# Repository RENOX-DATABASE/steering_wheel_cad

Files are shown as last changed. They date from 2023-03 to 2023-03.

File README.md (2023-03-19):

# Steering Wheel CAD DATA and Manual
The purpose is to share technology and knowledge, and it is for non-commercial purposes.

**Copyright 2023, RENOX**</br>
Subject to the existing rights of third parties, RENOX is the owner of the copyright in this work, and no portion hereof is to be copied, reproduced, or disseminated without the prior written consent of RENOX.

---
**GitLink**<br>
**Designed by RENOX**

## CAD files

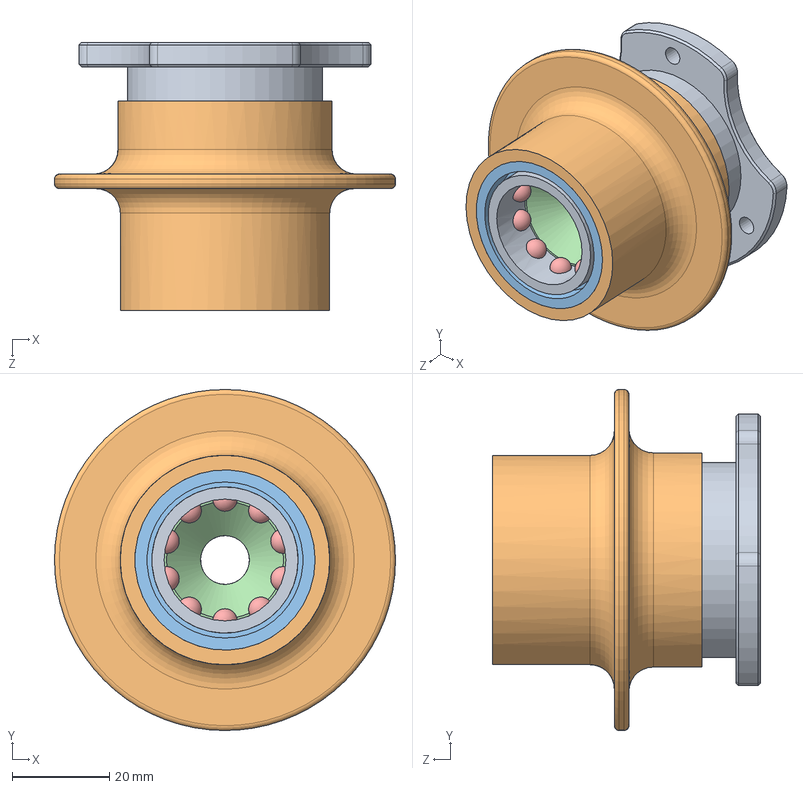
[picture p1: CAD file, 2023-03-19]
Quick Release 1.SLDASM
70.0 x 70.0 x 55.0 mm
Spring 1
Spring 2

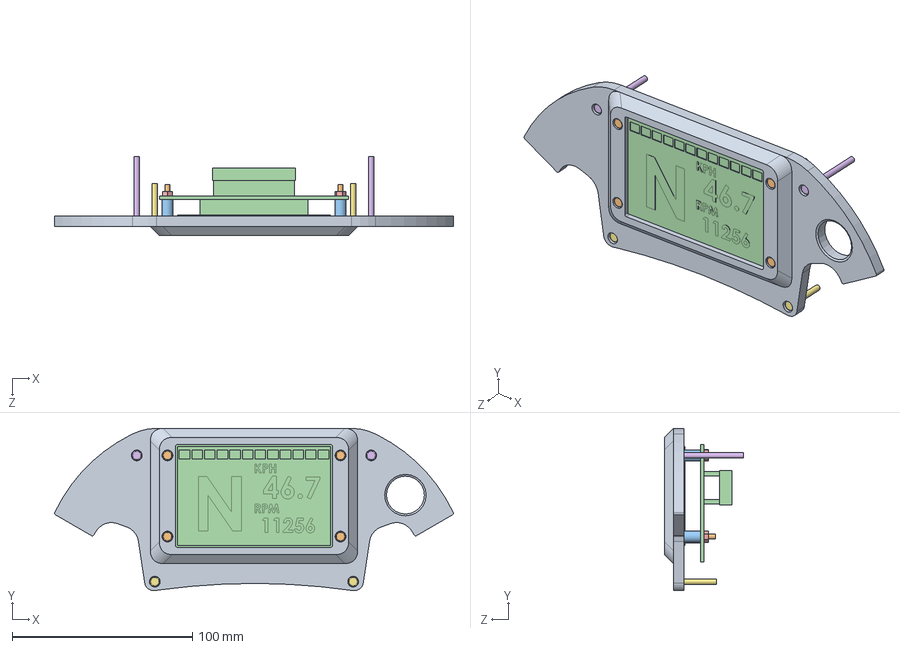
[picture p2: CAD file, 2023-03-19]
RF019 SWMB&AM.SLDASM
221.3 x 90.0 x 44.0 mm
RF019 SWMB kai
M3 25 Bolt x 4
RF018 Spacer for SWMB[M3 9] x 4
RF019 AC kai Display
M3 Nat x 4
M3 35 Bolt x 2
M3 20 Bolt x 2

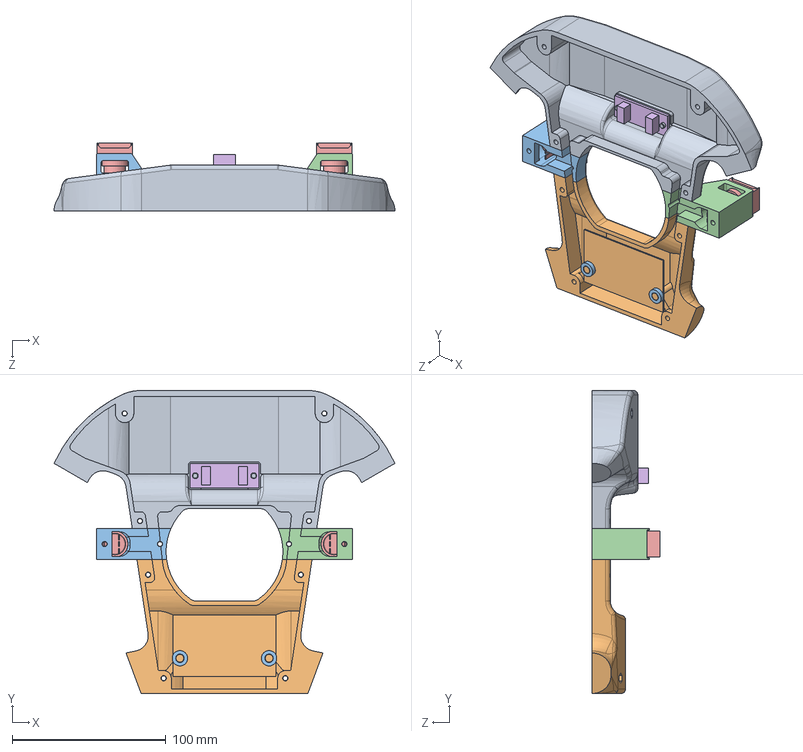
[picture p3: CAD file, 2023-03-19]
RF019 SWB&PSM.SLDASM
221.9 x 197.3 x 44.5 mm
RF019 SWB kai B1
RF019 SWB kai B3
RF019 SWB PSMB2L kai
RF019 SWB PSMB2R kai
RF018 IDEC Switch x 2
RF019 CC
M3 Nat x 12
M2 Nat x 2
M2 8 Bolt x 2
RF019 SC kai
RF018 Spacer for Shifter Circle[Φ5 3] x 2

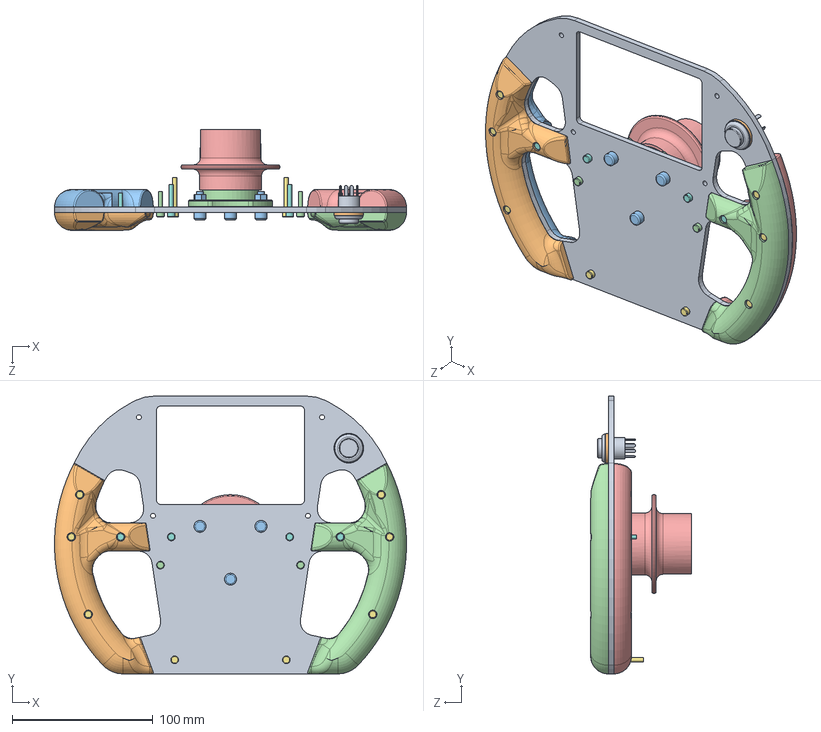
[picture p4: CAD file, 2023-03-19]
RF019 SWCP&G.SLDASM
249.9 x 197.3 x 71.5 mm
RF019 SWCP kai
RF019 SWG kai LF
RF019 SWG kai LR
RF019 SWG kai RF
RF019 SWG kai RR
M3 Nat x 6
M3 25 Bolt x 8
M3 20 Bolt x 4
RF018 Paddle Shift Adapt Switch
RF018 Spacer for PSA Switch
M5 20 Bolt x 3
Spring 1
Spring 2
M5 Nat x 3
M3 15 Bolt x 2

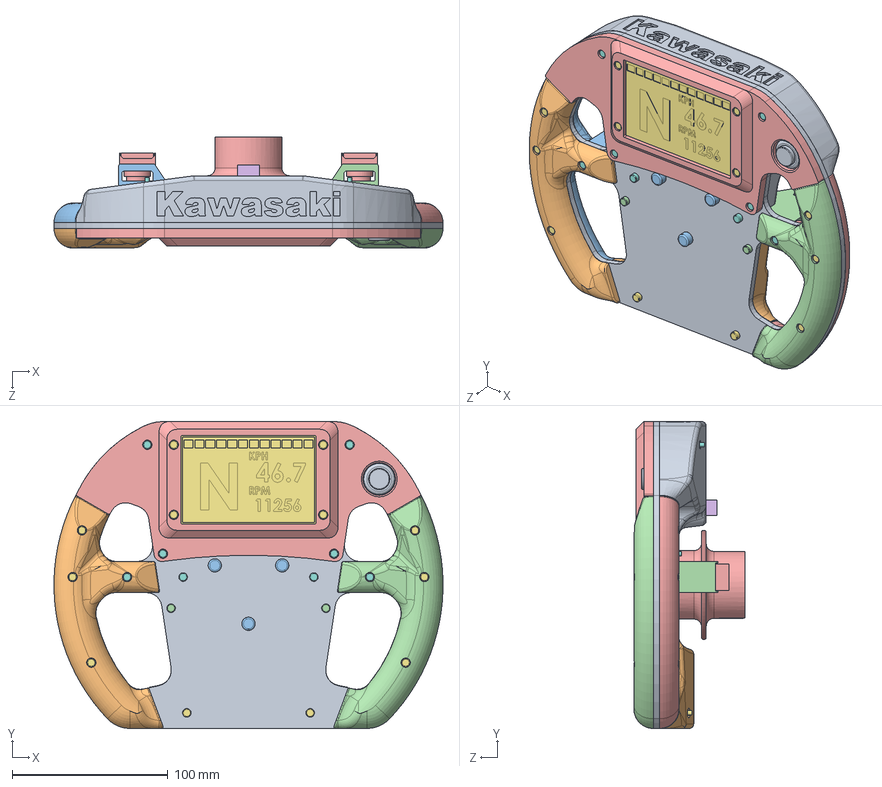
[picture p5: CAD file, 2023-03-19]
RF019 SW Assem.SLDASM
249.9 x 197.3 x 71.5 mm
RF019 SWCP kai
RF019 SWG kai LF
RF019 SWG kai LR
RF019 SWG kai RF
RF019 SWG kai RR
M3 Nat x 22
M3 25 Bolt x 12
M3 20 Bolt x 6
RF018 Paddle Shift Adapt Switch
RF018 Spacer for PSA Switch
M5 20 Bolt x 3
Spring 1
Spring 2
M5 Nat x 3
M3 15 Bolt x 2
RF019 SWMB kai
RF018 Spacer for SWMB[M3 9] x 4
RF019 AC kai Display
M3 35 Bolt x 2
RF019 SWB kai B1
RF019 SWB kai B3
RF019 SWB PSMB2L kai
RF019 SWB PSMB2R kai
RF018 IDEC Switch x 2
RF019 CC
M2 Nat x 2
M2 8 Bolt x 2
RF019 SC kai
RF018 Spacer for Shifter Circle[Φ5 3] x 2

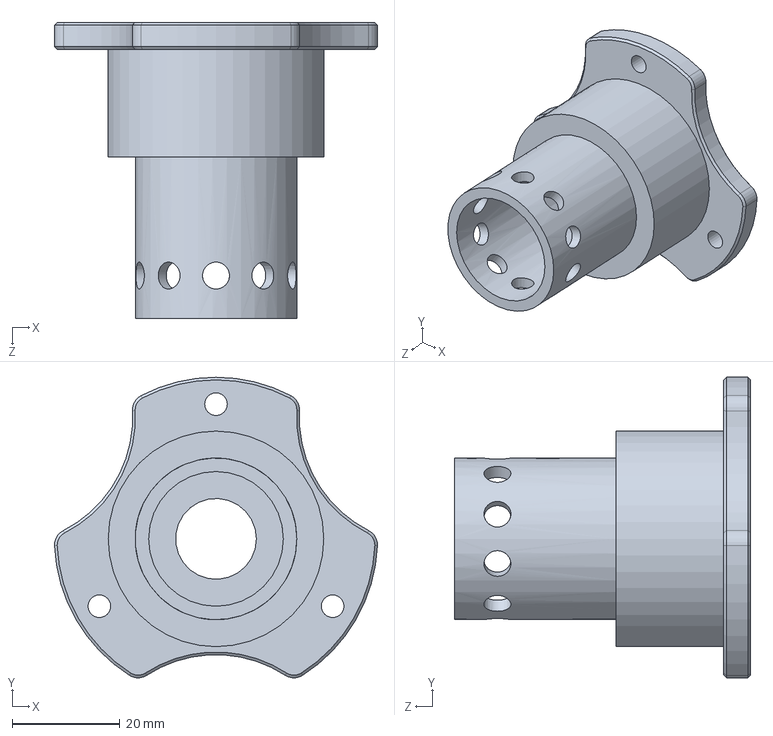
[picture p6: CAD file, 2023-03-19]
1-1.SLDPRT
59.9 x 55.8 x 55.0 mm

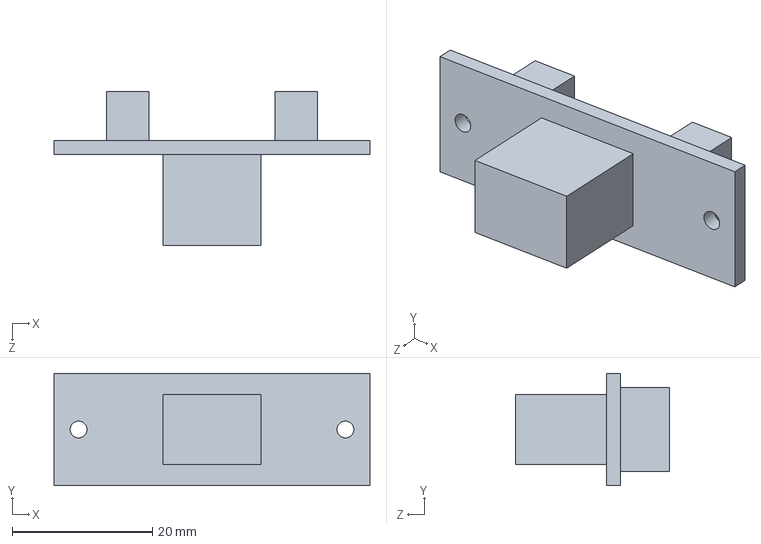
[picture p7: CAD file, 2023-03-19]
RF019 CC.SLDPRT
45.0 x 16.0 x 22.0 mm

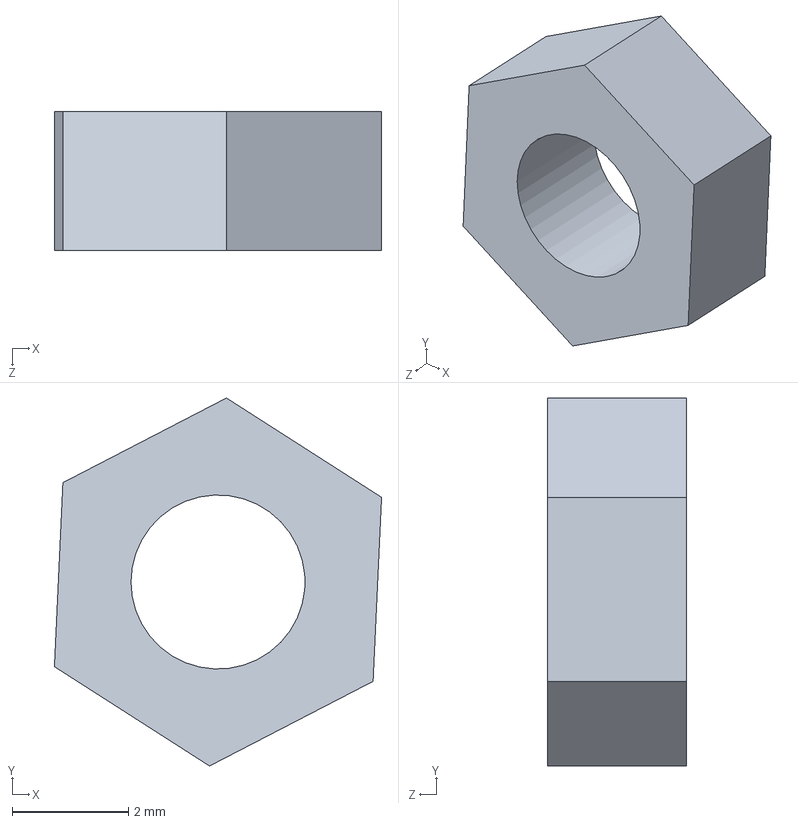
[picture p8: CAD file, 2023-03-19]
M3 Nat.SLDPRT
5.64 x 6.34 x 2.40 mm

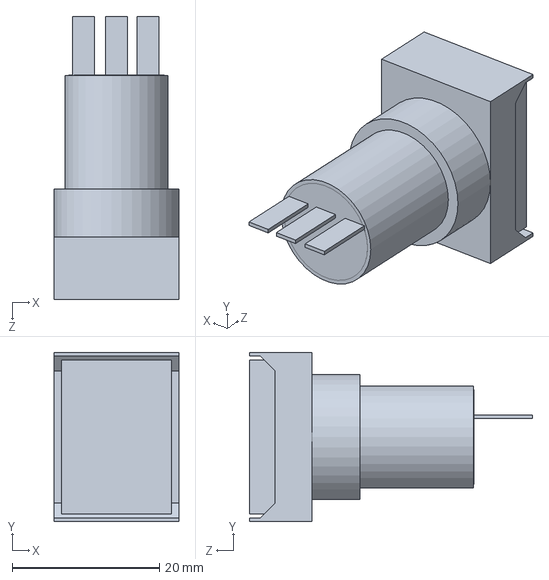
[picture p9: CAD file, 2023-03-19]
RF018 IDEC Switch.SLDPRT
17.0 x 23.0 x 38.5 mm

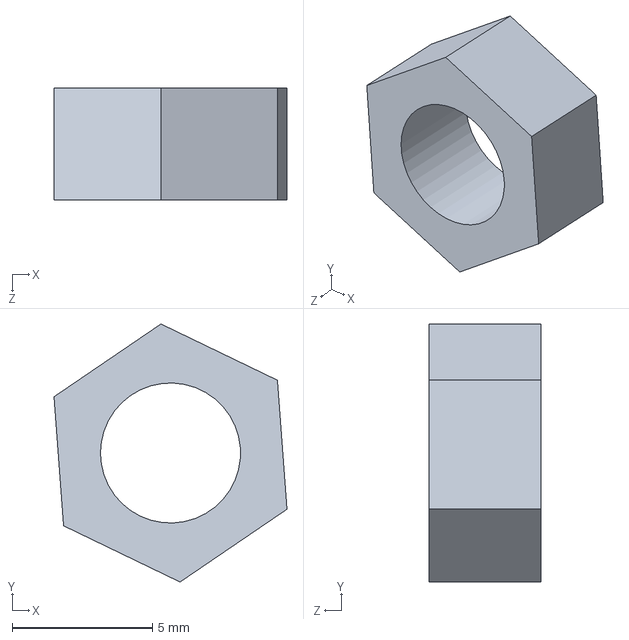
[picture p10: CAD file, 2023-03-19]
M5 Nat.SLDPRT
8.32 x 9.21 x 4.00 mm

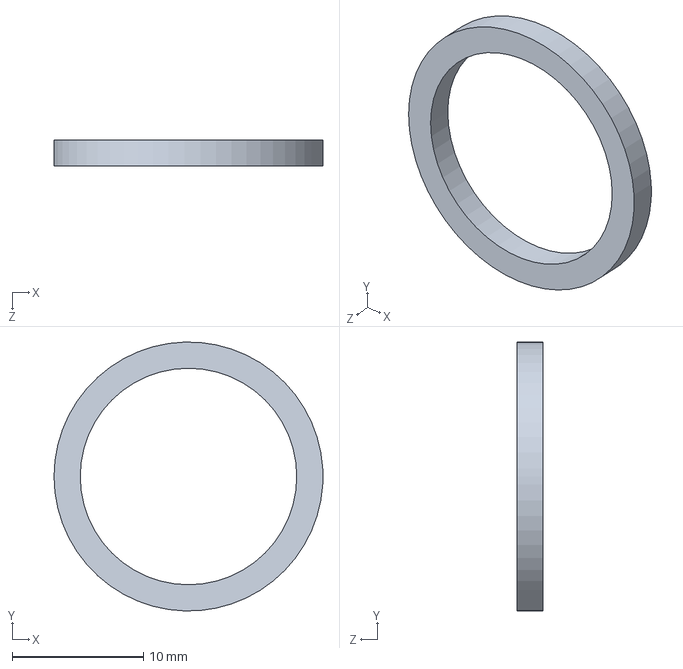
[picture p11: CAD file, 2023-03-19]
RF018 Spacer for PSA Switch.SLDPRT
20.5 x 20.5 x 2.00 mm

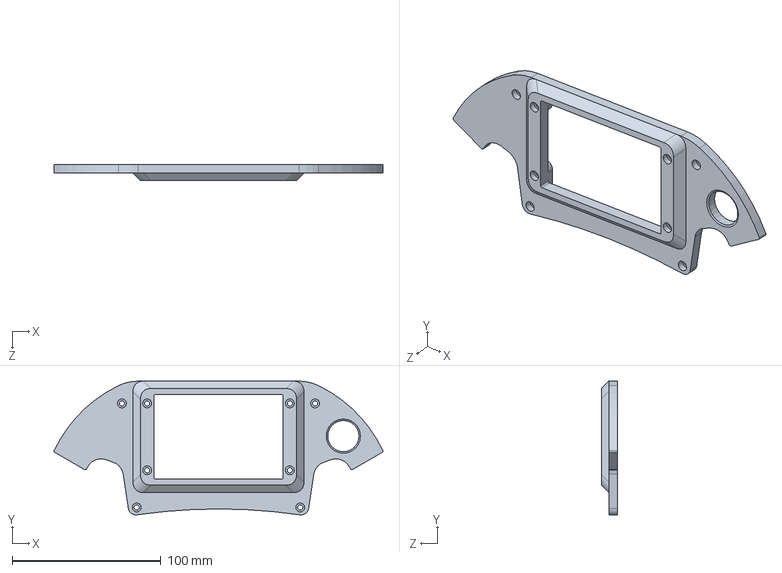
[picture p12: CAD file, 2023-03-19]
RF019 SWMB kai.SLDPRT
221.3 x 90.0 x 11.0 mm

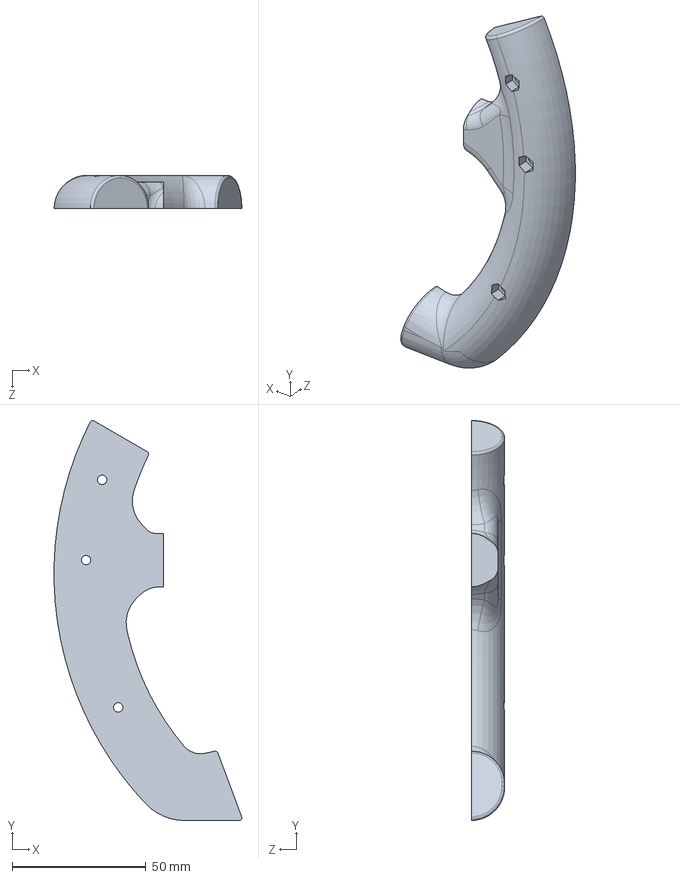
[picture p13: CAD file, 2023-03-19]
RF019 SWG kai LR.SLDPRT
70.2 x 149.4 x 12.5 mm

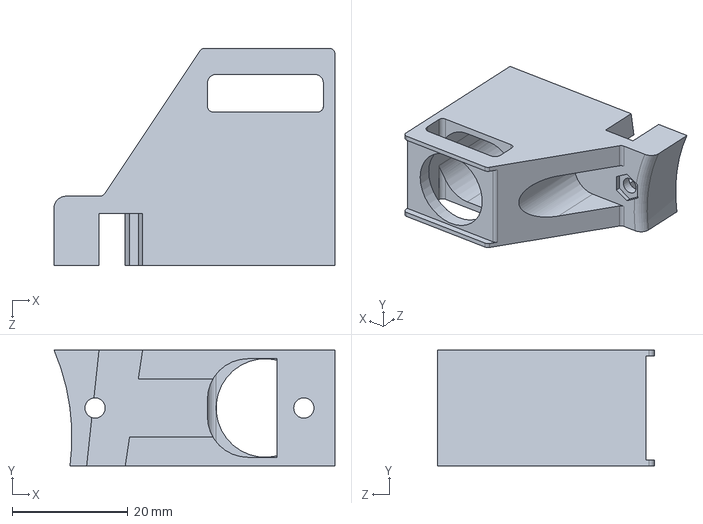
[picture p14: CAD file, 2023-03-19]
RF019 SWB PSMB2R kai.SLDPRT
48.5 x 20.0 x 37.5 mm

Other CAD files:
RF019 SWG kai RR.SLDPRT
Spring 1.SLDPRT
RF018 Spacer for Shifter Circle[Φ5 3].SLDPRT
1-2.SLDPRT
1-3.SLDPRT
1-4.SLDPRT
1-5.SLDPRT
M2 8 Bolt.SLDPRT
M2 Nat.SLDPRT
M3 15 Bolt.SLDPRT
M3 20 Bolt.SLDPRT
M3 25 Bolt.SLDPRT
M3 35 Bolt.SLDPRT
M5 20 Bolt.SLDPRT
RF018 Paddle Shift Adapt Switch.SLDPRT
RF018 Spacer for SWMB[M3 9].SLDPRT
RF019 AC kai Display.SLDPRT
RF019 SC kai.SLDPRT
RF019 SWB PSMB2L kai.SLDPRT
RF019 SWB kai B1.SLDPRT
RF019 SWB kai B3.SLDPRT
RF019 SWCP kai.SLDPRT
RF019 SWG kai LF.SLDPRT
RF019 SWG kai RF.SLDPRT
Spring 2.SLDPRT

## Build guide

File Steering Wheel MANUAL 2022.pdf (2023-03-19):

# S T E E R I N G W H E E L M A N U A L 2 0 2 2

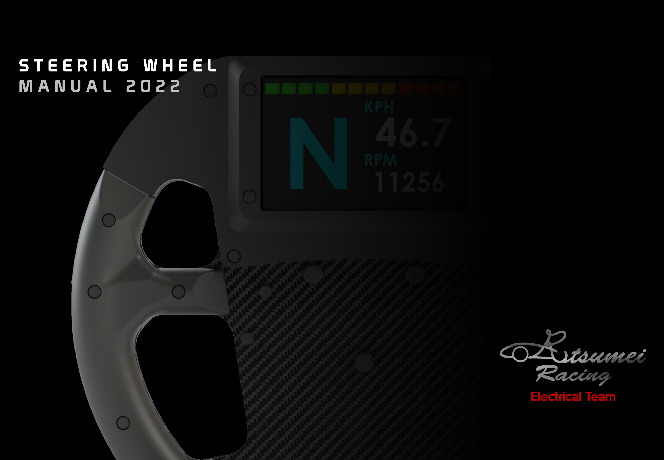
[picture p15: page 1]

## Electrical Team

# C o n t e n t s

このマニュアルはRitsumei Racingで設計されたステアリング ホイールの概要と組み立て方法を説明するものである。当初はス マートフォンにメーターを表示するアプリを開発しようとしてい た。メーターの目的はエンデュランスで電光掲示板に表示される ラップタイムをドライバー以外の人がスマートフォンに送信する ことであったが、完成しなかった。今回、アプリ開発や通信が難 しいと考え、マイコンを使った自作ディスプレイメーターに変更 し製作した。今回の目的はアクセラレーションにおけるシフトポ ジションと回転数の表示、スキッドパッドにおける車速表示、 オートクロス・エンデュランスにおけるシフトポジション表示で ある。

ステアリングホイールの構成部品について以下に示す。
ステアリングホイールのフレームはカーボンシートを16枚積 層しKitMillの超硬合金エンドミルで切して製作されたが、製作過 程で少し反ってしまっている。
PCBはElecrowに発注した。ただし、素子のはんだ付けは Elecrowでは行われない。
グリップやカバーなどは全てAIOL(イーストウィング1F)の3D プリンター(MakerBot)で製作した。
締結部品はねじの山崎で購入し、スイッチ類はMISUMIで購入 した。他の部品は適宜購入した。

P C B
Connector Module
Shifter Module
Display Module
S y s t e m
Indicator System (RF-018)
Indicator System (RF-019)
Steering Wheel
F u t u r e W o r k
Insert Nut化
STM32 Micro Computer化
LEDタコメータのチップLED化
電源安定化供給
外部接続コネクタのRAPFIX Quick Release化 F i n i s h e d P a r t

## Key

## Manufacturing Error

## Warning

## Point

## Contact Us

## https://qiita.com/RENOX https://github.com/RENOX-DATABASE

Ritsumei Racing
Designed by RENOX

# PCB

# Connector Module

## PCB

2. Power & Others Connector 4 Pin XH Connector × 2

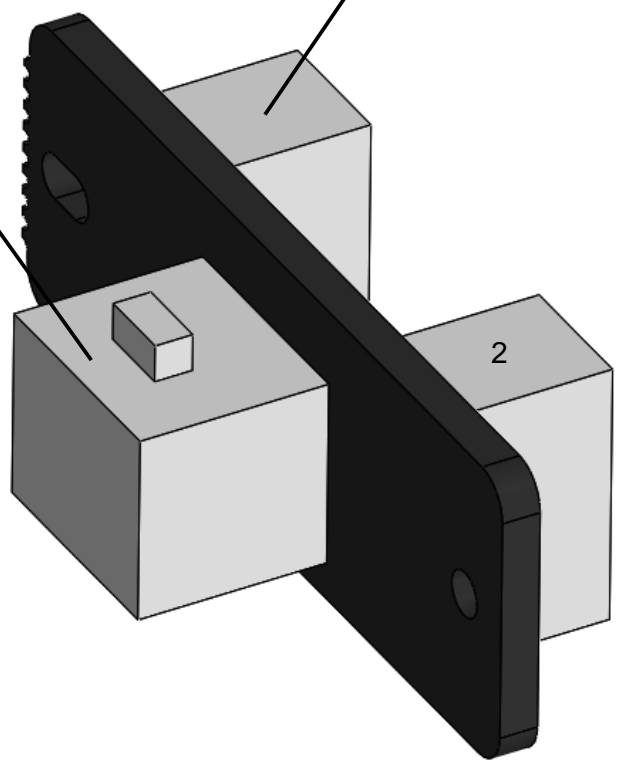
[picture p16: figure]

1. Outside Connector
Molex 6 Pin Mini-Fit-Jr
① | ②
④ | ⑤

③

1
2

※順不同(EAGLEデータ参照)
① 7~12 V
② GND
③ Shift Position Sensor
④ RPM Sensor
⑤ Solenoid Valve 1
⑥ Solenoid Valve 2

⑦
⑧
⑨
⑩

⑥

⑦ ⑧ ⑨ ⑩

Display Module及びShifter
Module のPower&Others Co
nectorに合わせること。

# Connector Module

## PCB

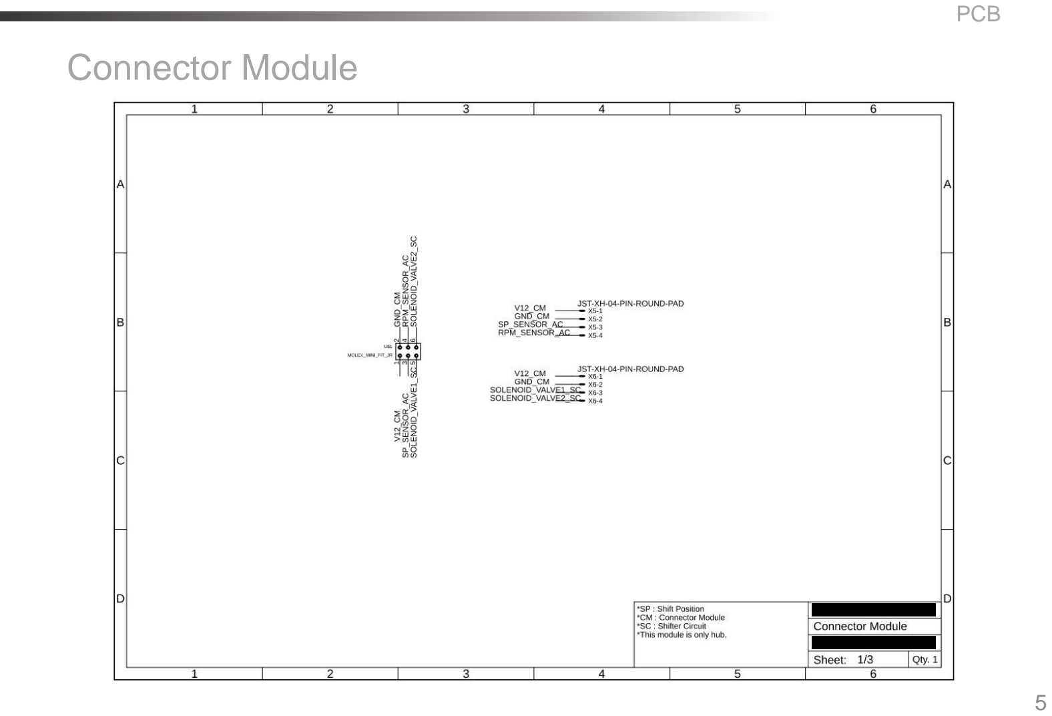
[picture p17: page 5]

# Shifter Module

## PCB

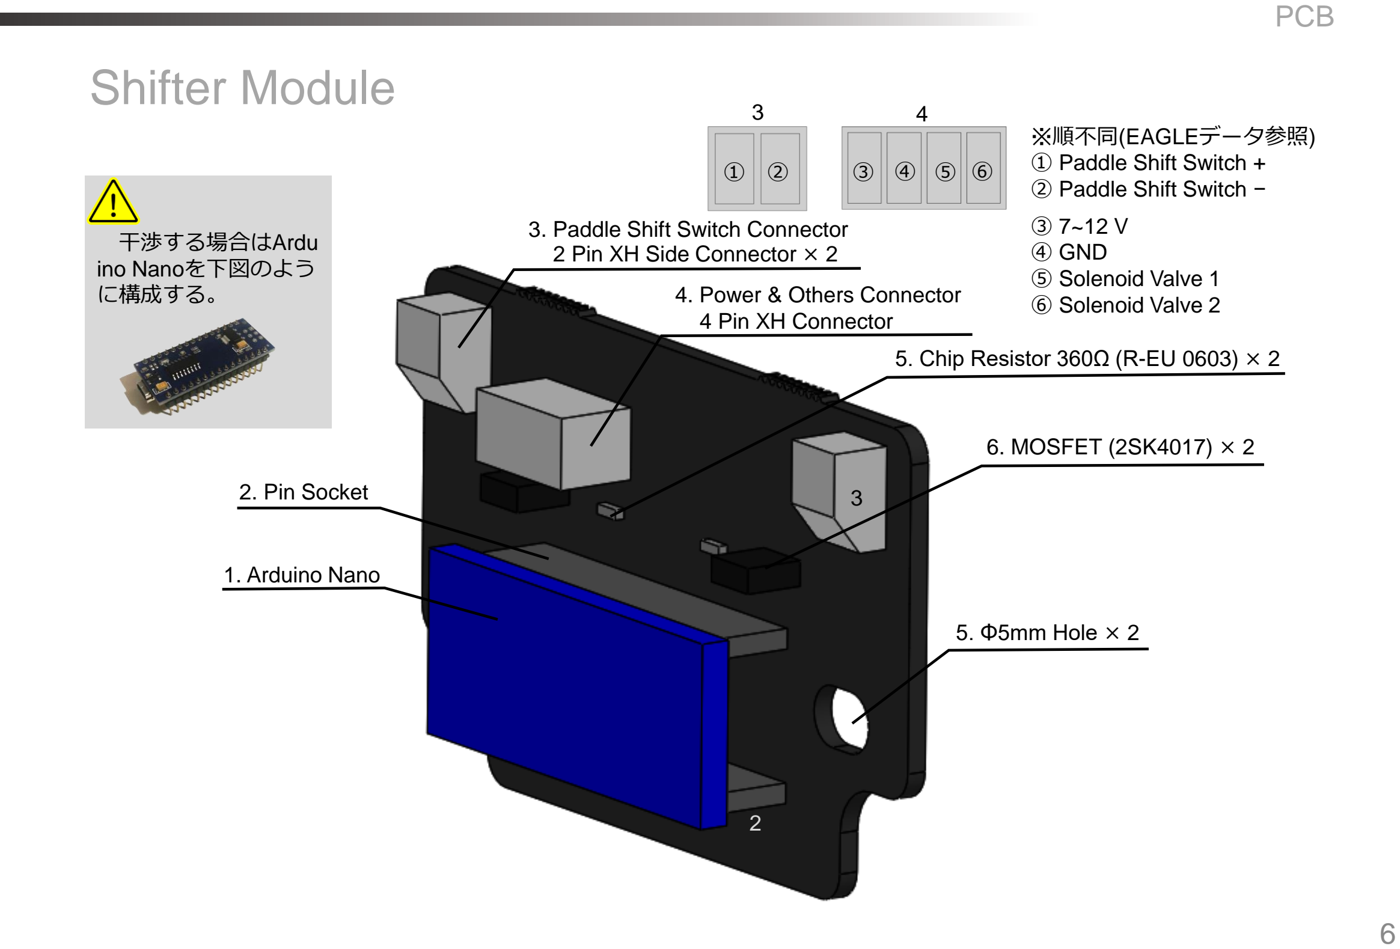
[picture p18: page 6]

5. Φ5mm Hole × 2
2. Pin Socket
1. Arduino Nano
3. Paddle Shift Switch Connector 2 Pin XH Side Connector × 2
4. Power & Others Connector 4 Pin XH Connector

3

2

干渉する場合はArdu
ino Nanoを下図のよう
に構成する。
6. MOSFET (2SK4017) × 2
5. Chip Resistor 360Ω (R-EU 0603) × 2
① ② | ③ ④ ⑤
3 | 4
※順不同(EAGLEデータ参照)
① Paddle Shift Switch +
② Paddle Shift Switch −

③ 7~12 V
④ GND
⑤ Solenoid Valve 1
⑥ Solenoid Valve 2

⑥

# Shifter Module

## PCB

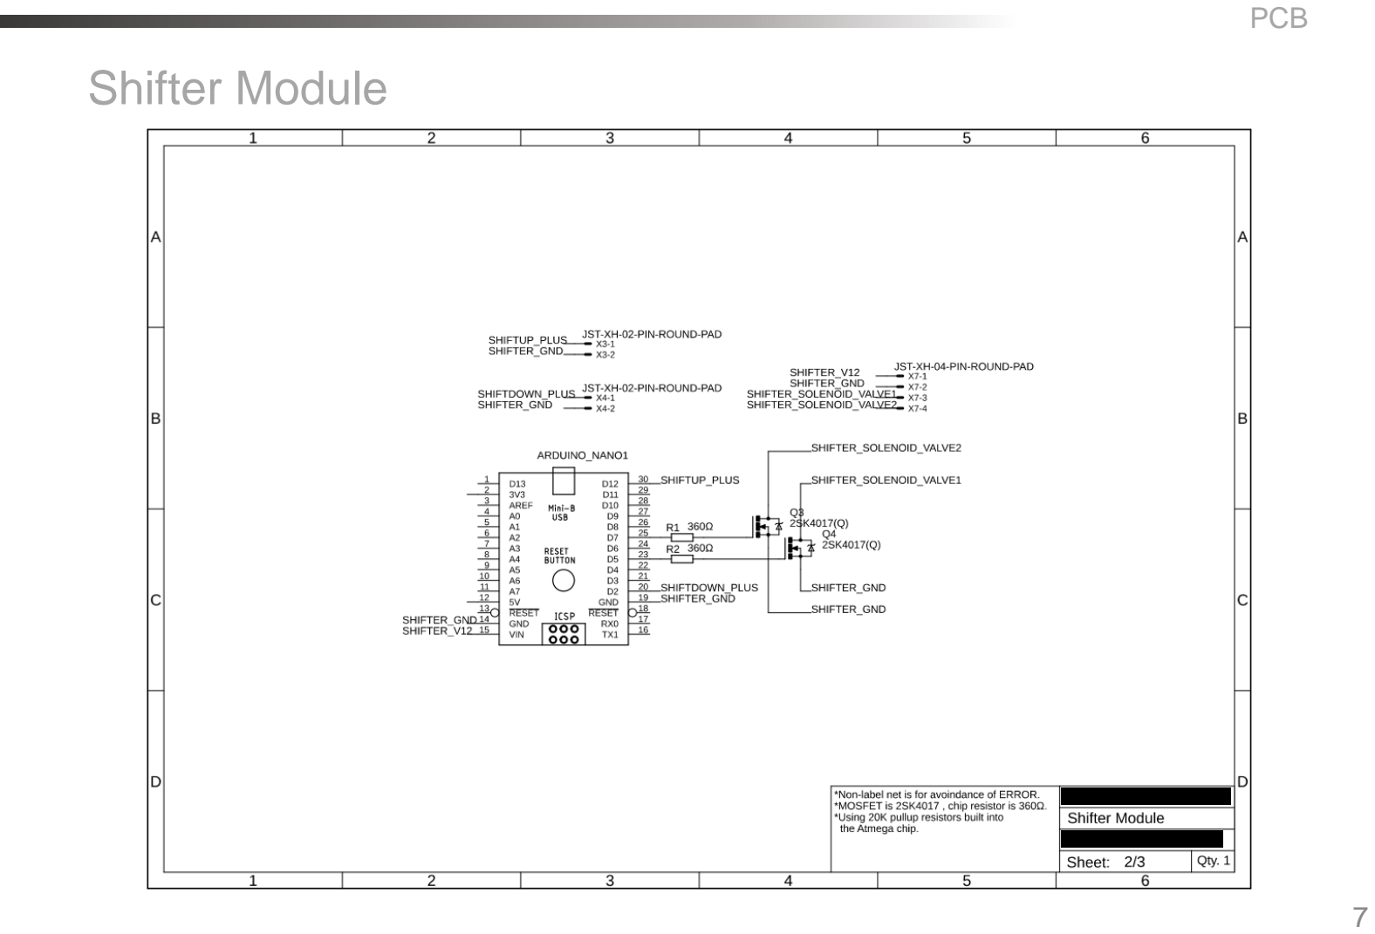
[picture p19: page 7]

# Display Module

## PCB

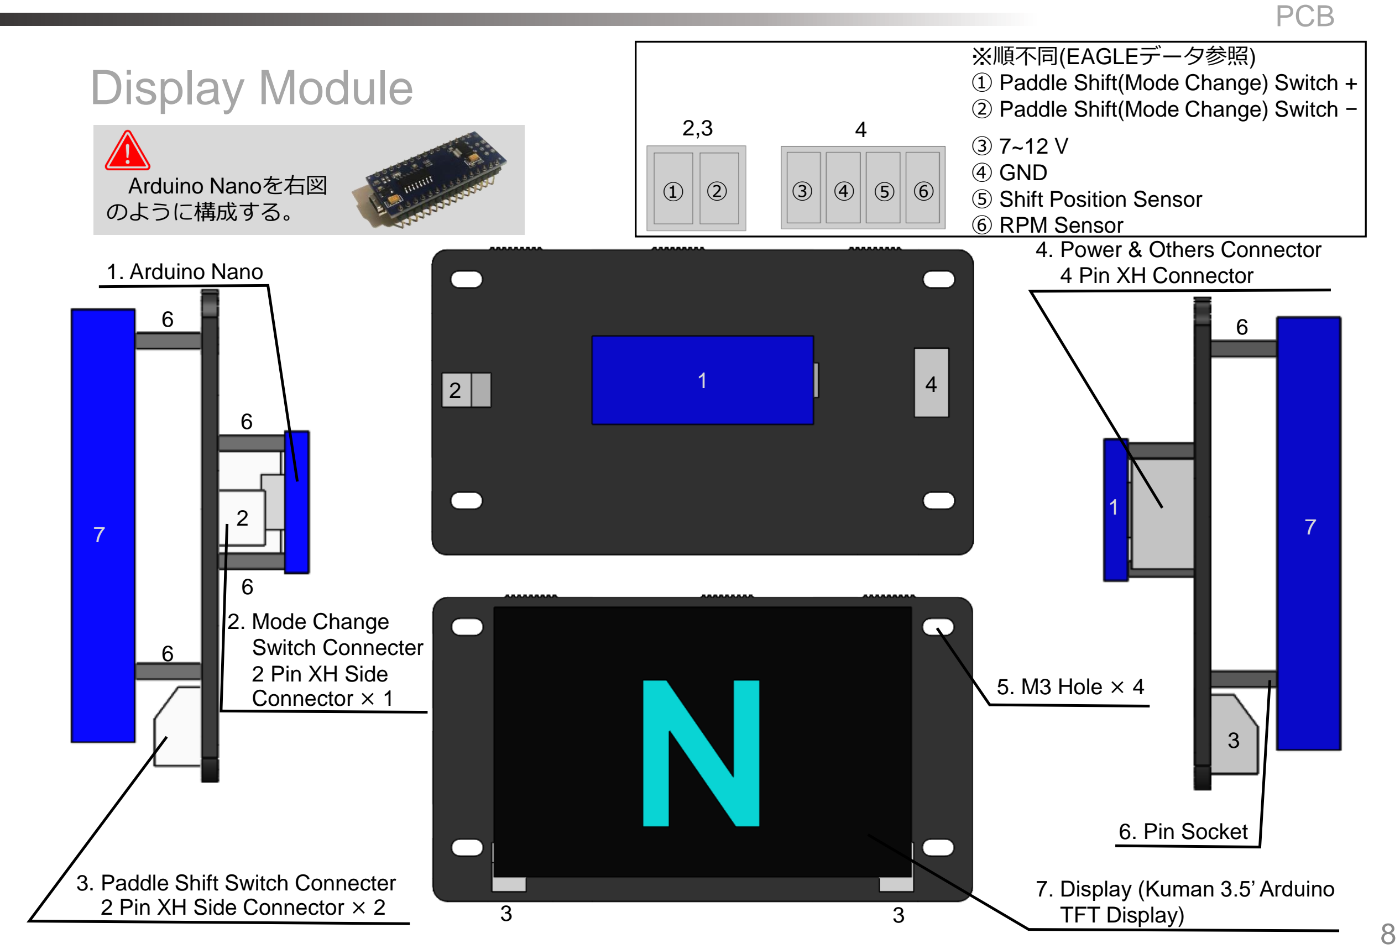
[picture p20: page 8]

Arduino Nanoを右図
のように構成する。
7. Display (Kuman 3.5’ Arduino TFT Display)
1. Arduino Nano
3. Paddle Shift Switch Connecter 2 Pin XH Side Connector × 2
6. Pin Socket

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
3 | 3
1 | 4
5. M3 Hole × 4
4. Power & Others Connector 4 Pin XH Connector

7

7

1

① ② | ③ ④ ⑤ ⑥
2,3 | 4

※順不同(EAGLEデータ参照)
① Paddle Shift(Mode Change) Switch + ② Paddle Shift(Mode Change) Switch −

③ 7~12 V
④ GND
⑤ Shift Position Sensor
⑥ RPM Sensor
2. Mode Change
Switch Connecter
2 Pin XH Side
Connector × 1

# Display Module

## PCB

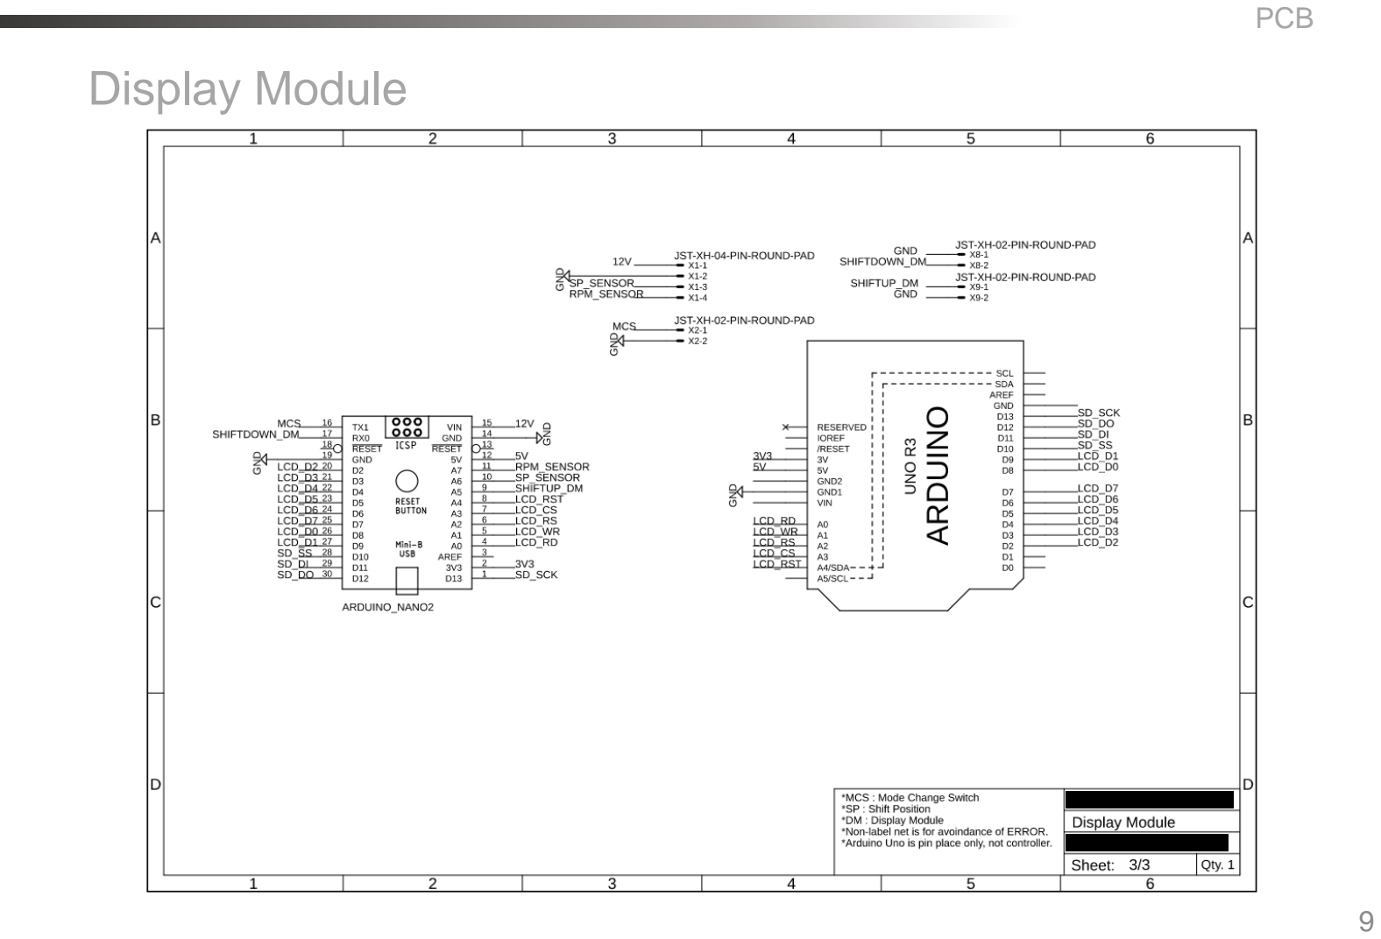
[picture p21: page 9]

# System

# Indicator System (Old ver.)

## System

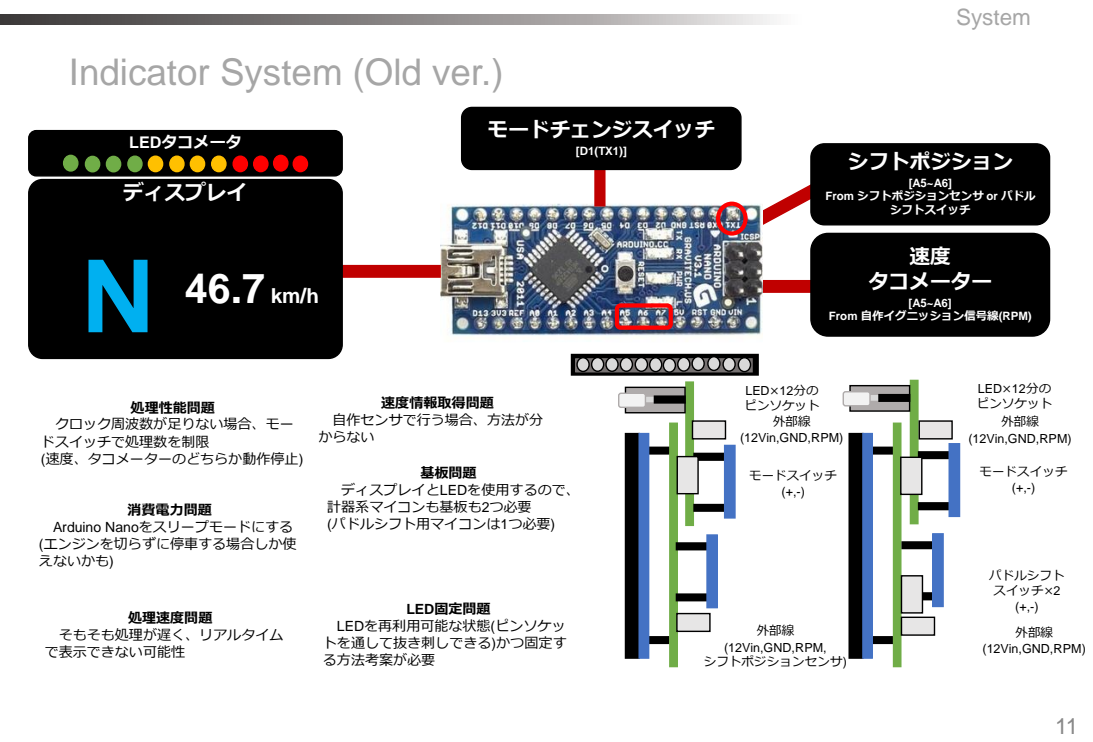
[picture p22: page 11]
シフトポジション; シフトスイッチ; 速度 タコメーター; ディスプレイ; 処理性能問題 クロック周波数が足りない場合、モー ドスイッチで処理数を制限 (速度、タコメーターのどちらか動作停止); 消費電力問題 Arduino Nanoをスリープモードにする (エンジンを切らずに停車する場合しか使 えないかも); 基板問題 ディスプレイとLEDを使用するので、 計器系マイコンも基板も2つ必要 (パドルシフト用マイコンは1つ必要); 速度情報取得問題 自作センサで行う場合、方法が分 からない; 処理速度問題 そもそも処理が遅く、リアルタイム で表示できない可能性; モードスイッチ; 外部線; (12Vin,GND,RPM, シフトポジションセンサ); パドルシフト スイッチ×2; (12Vin,GND,RPM); LEDタコメータ; LED×12分の ピンソケット; LED×12分の ピンソケット 外部線; LED固定問題 LEDを再利用可能な状態(ピンソケッ トを通して抜き刺しできる)かつ固定す る方法考案が必要; モードチェンジスイッチ

From シフトポジションセンサ or パドル

From 自作イグニッション信号線(RPM)

# Indicator System (New ver.)

## System

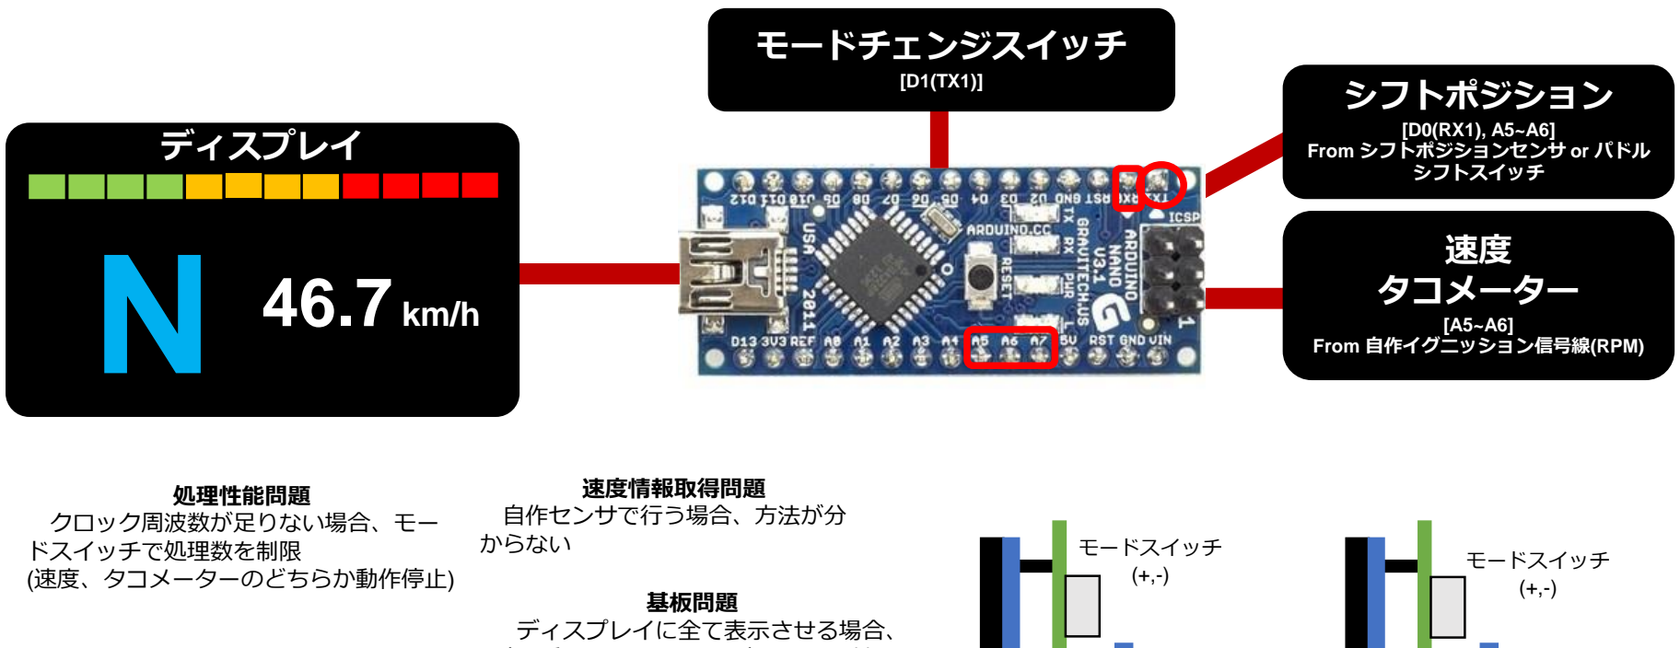
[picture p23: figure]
シフトポジション; [D0(RX1), A5~A6] From シフトポジションセンサ or パドル シフトスイッチ; 速度 タコメーター; [A5~A6] From 自作イグニッション信号線(RPM); ディスプレイ; 処理性能問題 クロック周波数が足りない場合、モー ドスイッチで処理数を制限 (速度、タコメーターのどちらか動作停止); 基板問題 ディスプレイに全て表示させる場合、; 速度情報取得問題 自作センサで行う場合、方法が分 からない; モードスイッチ; モードチェンジスイッチ

消費電力問題
Arduino Nanoをスリープモードにする
(エンジンを切らずに停車する場合しか使
えないかも)

計器系マイコンは1つで済むため、基
板も1枚で済み簡素化が可能
(パドルシフト用マイコンが1つ必要)

処理速度問題
そもそも処理が遅く、リアルタイム
で表示できない可能性
(LEDよりも反応遅い)

外部線
(12Vin,GND,RPM,
シフトポジションセンサ)

パドルシフト
スイッチ×2
(+,-)

外部線
(12Vin,GND,RPM)

# Steering Wheel

## System

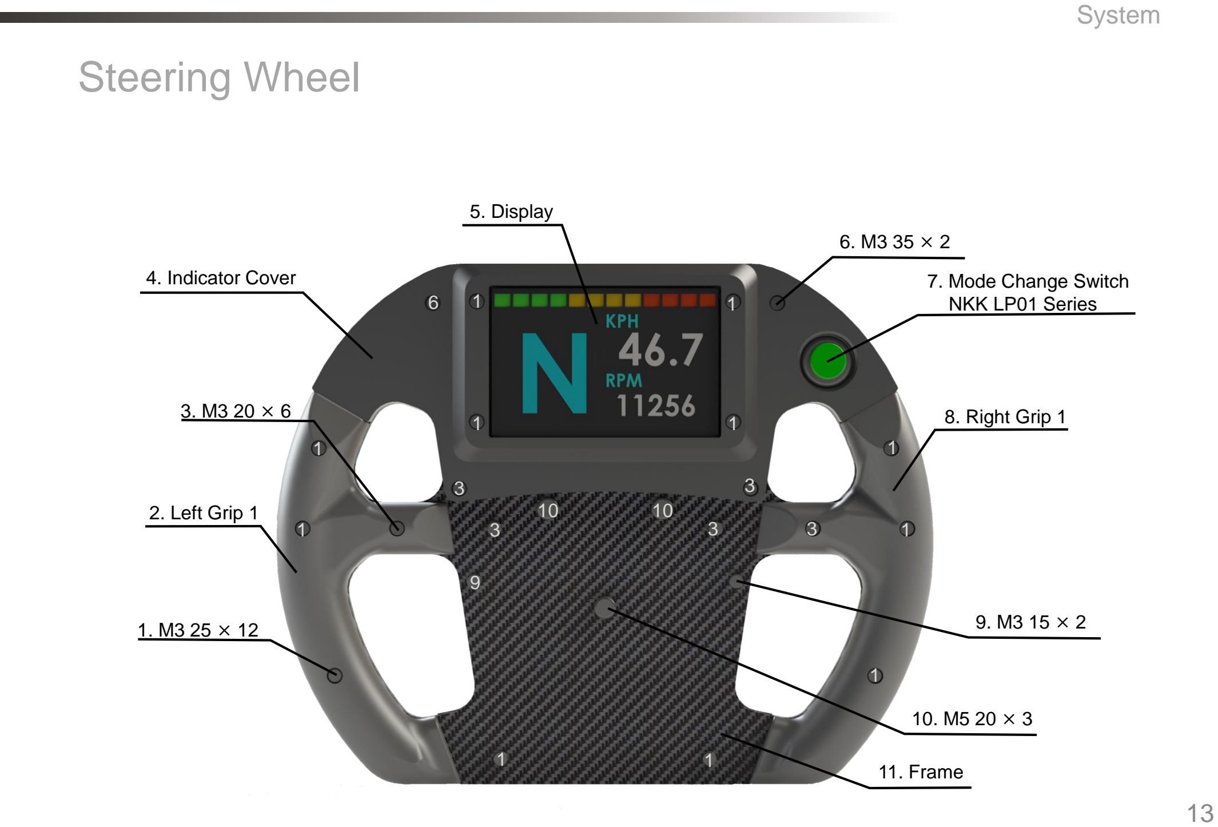
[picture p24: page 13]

2. Left Grip 1
1. M3 25 × 12
4. Indicator Cover
8. Right Grip 1
11. Frame
7. Mode Change Switch
NKK LP01 Series
3. M3 20 × 6
5. Display
6. M3 35 × 2
10. M5 20 × 3
9. M3 15 × 2

1

1

1 | 1

1

1

1

1

1

1 | 3 | 3 | 3 | 1
3 | 3

9

10 | 10

6

# Steering Wheel

## System

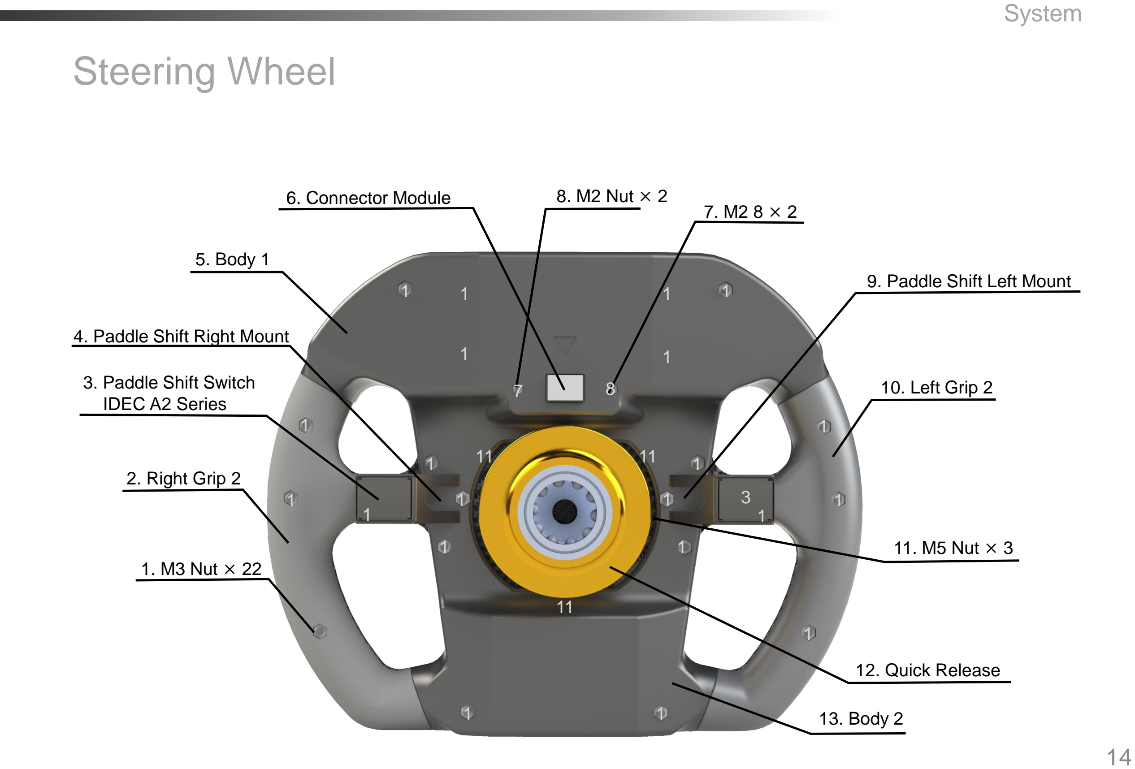
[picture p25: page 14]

2. Right Grip 2
5. Body 1
10. Left Grip 2
13. Body 2
9. Paddle Shift Left Mount
3. Paddle Shift Switch
IDEC A2 Series
6. Connector Module
7. M2 8 × 2
12. Quick Release

3

4. Paddle Shift Right Mount
8. M2 Nut × 2
1. M3 Nut × 22
7 | 8

1

1 | 1

1

1

11 1

1

1

1 | 1

11

1

1

11. M5 Nut × 3

11

1

1

1 | 1

1

1 | 1

# Steering Wheel

## System

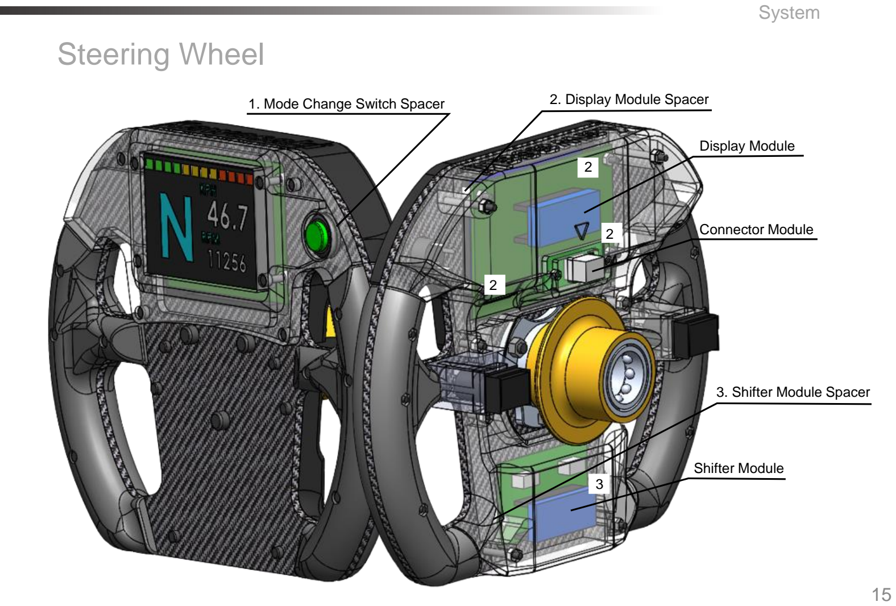
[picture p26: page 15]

Display Module

Connector Module

Shifter Module

2. Display Module Spacer
3. Shifter Module Spacer

2

3

2

2

1. Mode Change Switch Spacer

# Future Work

# Insert Nut化

## Future Work

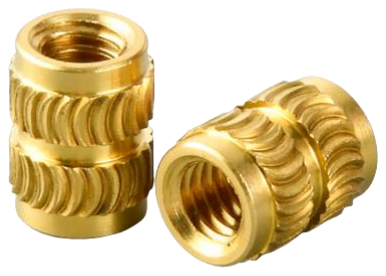
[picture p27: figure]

# STM32 Micro Computer化

## Future Work

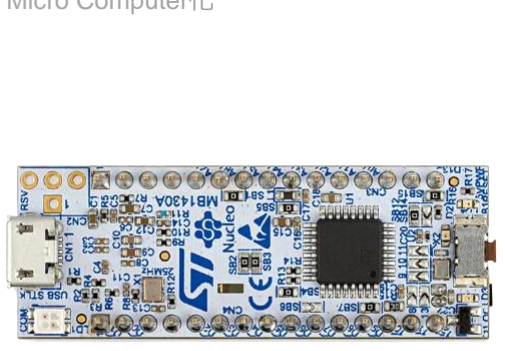
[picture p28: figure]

# LEDタコメータのチップLED化

## Future Work

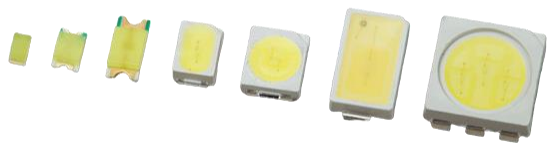
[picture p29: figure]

# 電源安定化供給

## Future Work

### https://tool-lab.com/pic-practice-11/ https://detail-infomation.com/3-terminal-regulator/

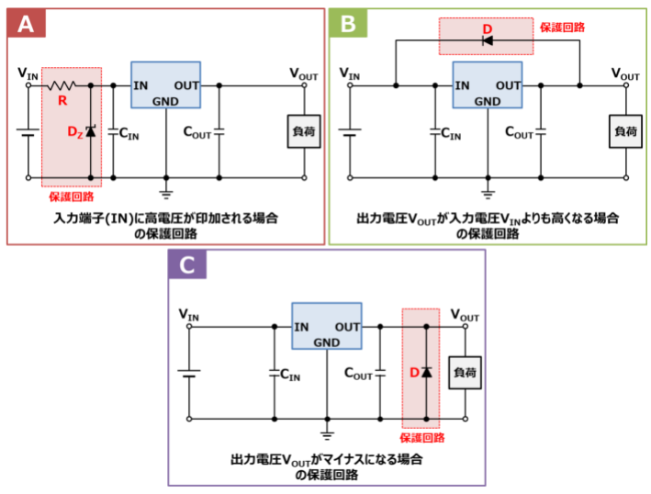
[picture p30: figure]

# 外部接続コネクタのRAPFIX Quick Release化

## Future Work

### https://www.worksbell.co.jp/products_detail/racing/

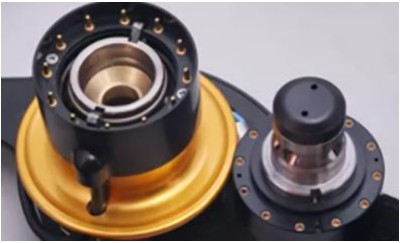
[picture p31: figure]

# Finished Part

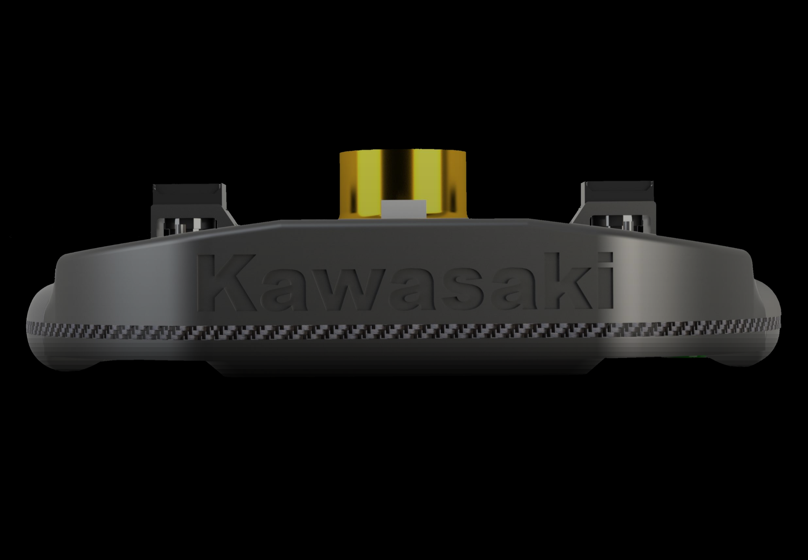
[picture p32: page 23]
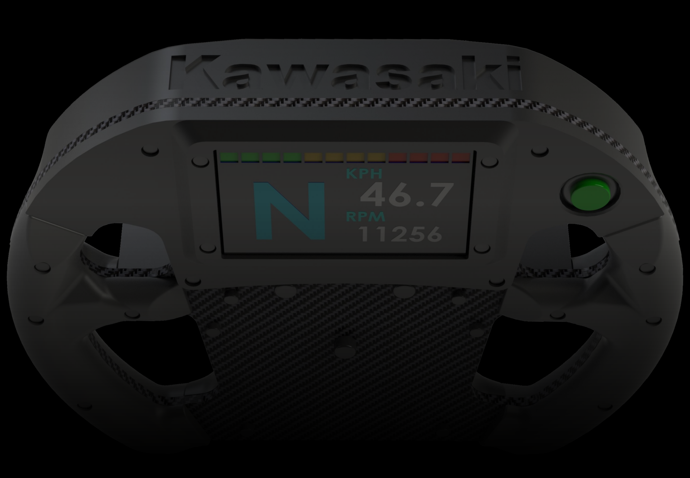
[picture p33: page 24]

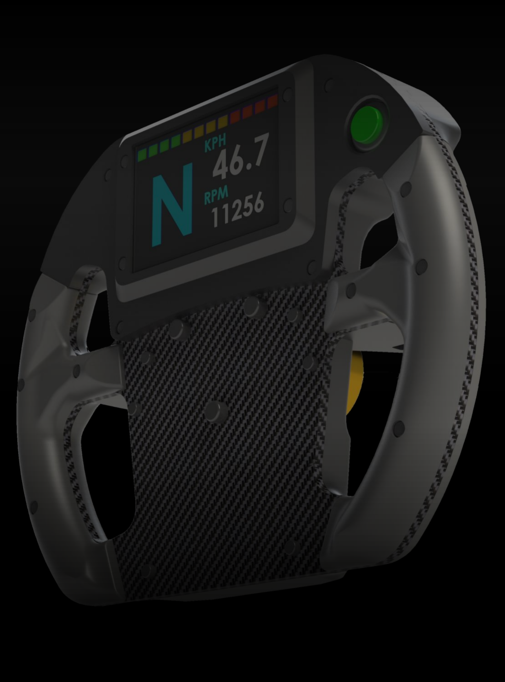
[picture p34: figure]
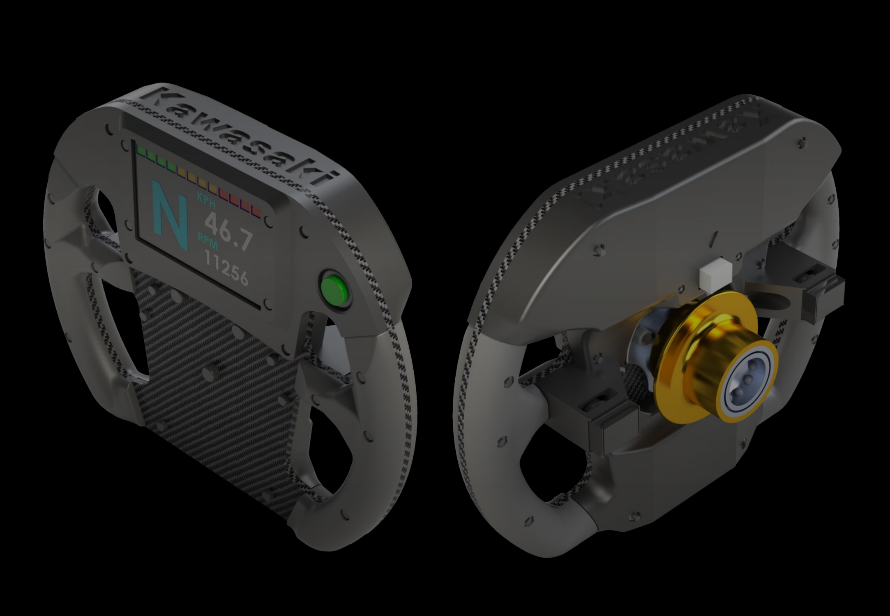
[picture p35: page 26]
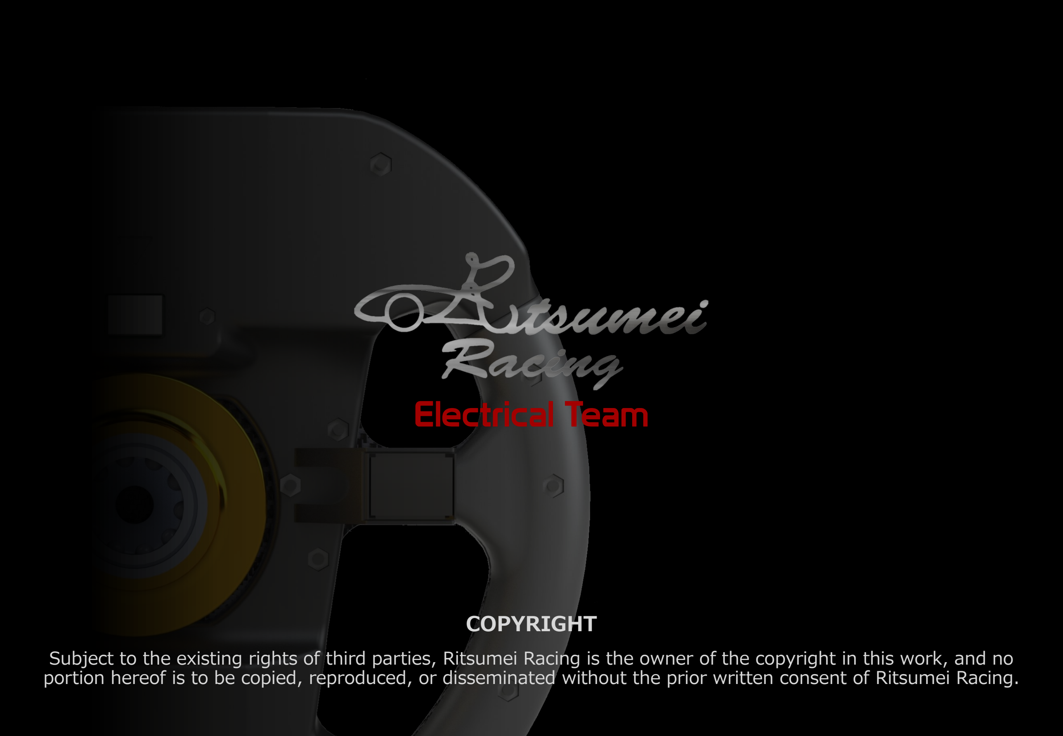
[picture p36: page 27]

2023/3/17

# Electrical Team

## COPYRIGHT

Subject to the existing rights of third parties, Ritsumei Racing is the owner of the copyright in this work, and no portion hereof is to be copied, reproduced, or disseminated without the prior written consent of Ritsumei Racing.
